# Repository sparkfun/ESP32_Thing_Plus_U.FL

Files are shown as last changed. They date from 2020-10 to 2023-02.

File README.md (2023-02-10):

SparkFun ESP32 Thing Plus (U.FL)
========================================

SparkFun ESP32 Thing Plus U.FL (https://www.sparkfun.com/products/17381)

[*SparkFun ESP32 Thing Plus U.FL (WRL-17381)*](https://www.sparkfun.com/products/17381)

The [SparkFun ESP32 Thing Plus (U.FL)](https://www.sparkfun.com/products/17381) is a comprehensive development platform for [Espressif's ESP32](https://espressif.com/en/products/hardware/esp32/overview). This board has the ESP32-WROOM-32EU version of the module which contains a U.FL connector for your antenna. Like the 8266 and ESP32 Thing, the ESP32 Thing Plus is a **WiFi**-compatible microcontroller with support for **Bluetooth low-energy** (i.e BLE, BT4.0, Bluetooth Smart), a Qwiic adapter, and 21 I/O pins. Add to that a rich set of peripherals ranging from capacitive touch sensors, SD card interface, Ethernet, high-speed SPI, UART, I2S and I<sup>2</sup>C.

Upgraded and easy to use, the Esp32 Thing Plus will help make it the foundation of IoT and connected projects for many years to come.

Repository Contents
-------------------

* **/Hardware** - Eagle design files (.brd, .sch)
* **/Hardware/Production** - Production panel files (gerbers, .brd)

Documentation
--------------
* **[Hookup Guide](https://learn.sparkfun.com/tutorials/esp32-thing-plus-hookup-guide)** - Basic hookup guide for the ESP32 Thing Plus.
* **[SparkFun Fritzing repo](https://github.com/sparkfun/Fritzing_Parts)** - Fritzing diagrams for SparkFun products.
* **[SparkFun Graphical Datasheets](https://github.com/sparkfun/Graphical_Datasheets)** -Graphical Datasheets for various SparkFun products.

Product Versions
----------------
* [WRL-17381](https://www.sparkfun.com/products/17381)- v1.0, Initial Release

License Information
-------------------

This product is _**open source**_! 

Please review the LICENSE.md file for license information. 

If you have any questions or concerns on licensing, please contact technical support on our [SparkFun forums](https://forum.sparkfun.com/viewforum.php?f=152).

Distributed as-is; no warranty is given.

- Your friends at SparkFun.

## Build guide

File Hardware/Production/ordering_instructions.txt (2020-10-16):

panel size, 131x191mm
PCB thickness, 1.6mm
number of layers, 4
soldermask color, Red
silkscreen color, White
oz copper, 1oz
finish, HASL lead free
stencils, top
pcs per panel, 15
min trace width, 0.2032mm / 0.0080in
min drill size, 0.2540mm / 0.0100in
filename to layer stackup 1/2/3/4: GTL, GL2, GL3, GBL

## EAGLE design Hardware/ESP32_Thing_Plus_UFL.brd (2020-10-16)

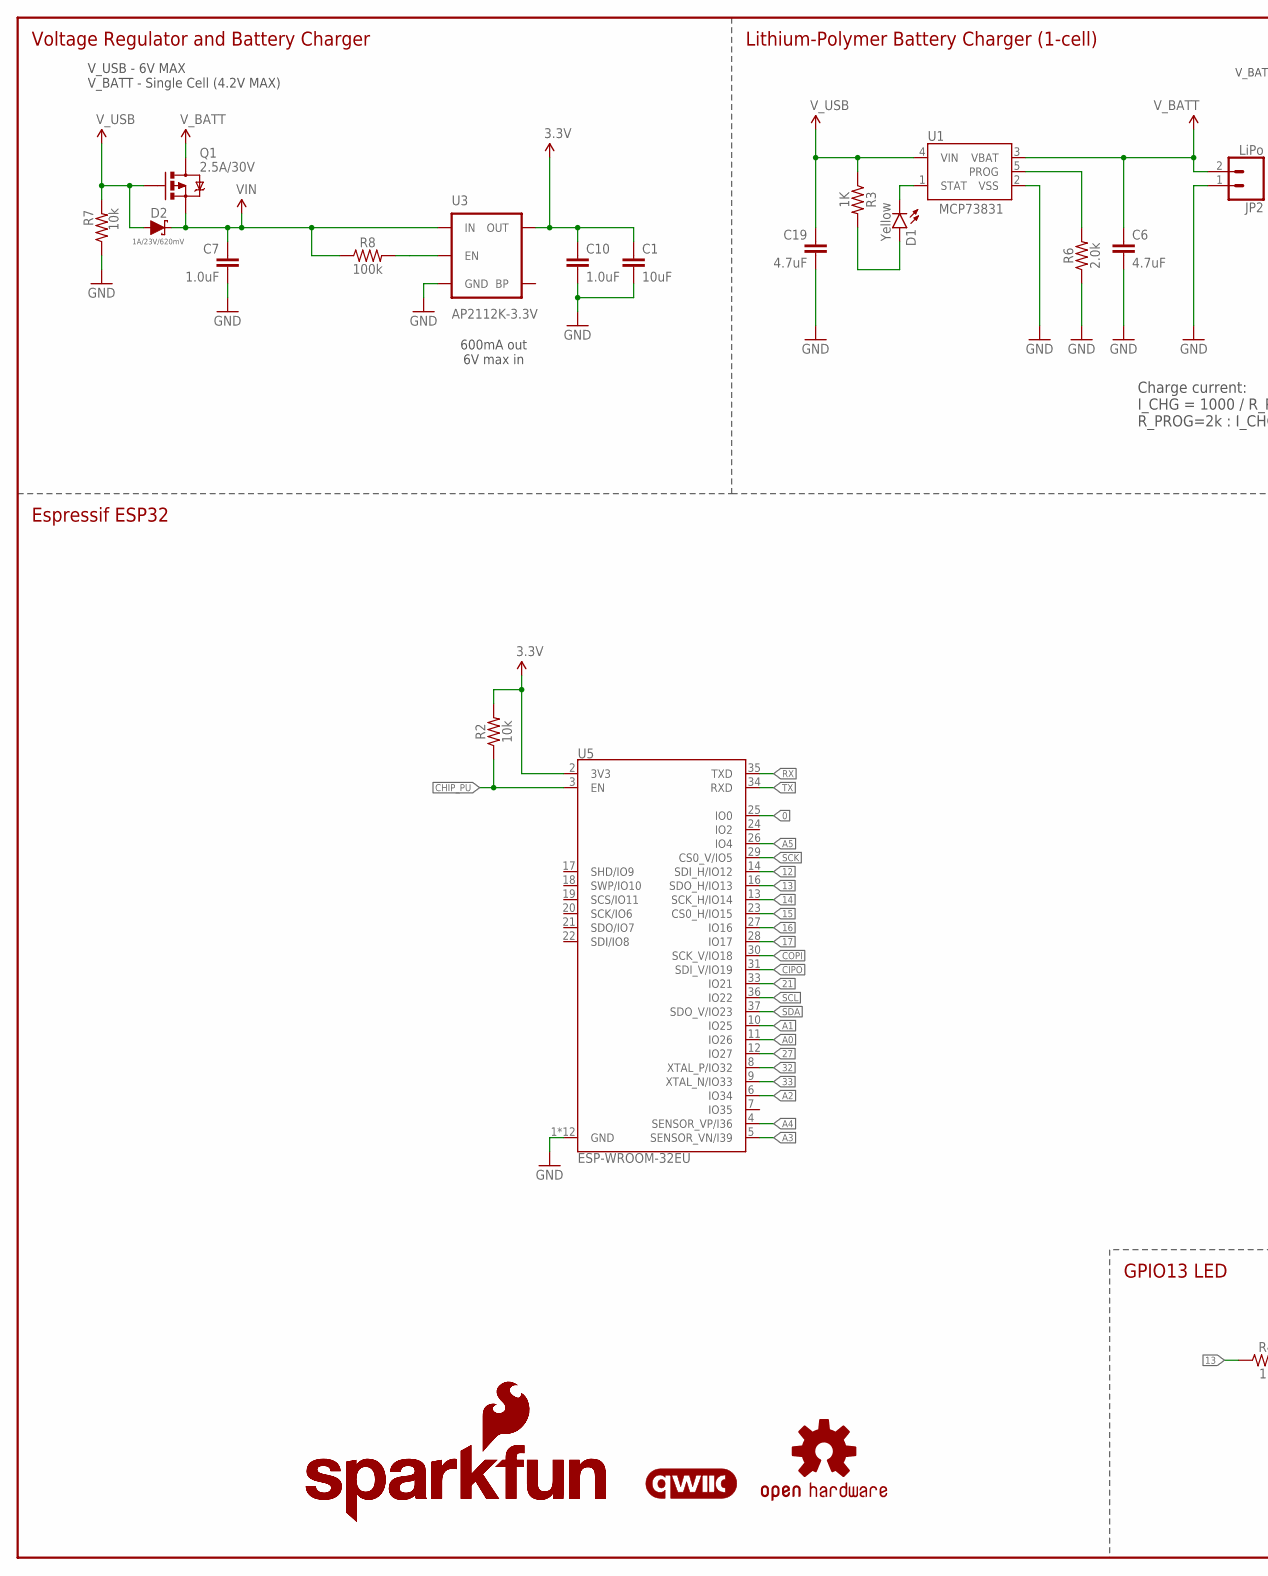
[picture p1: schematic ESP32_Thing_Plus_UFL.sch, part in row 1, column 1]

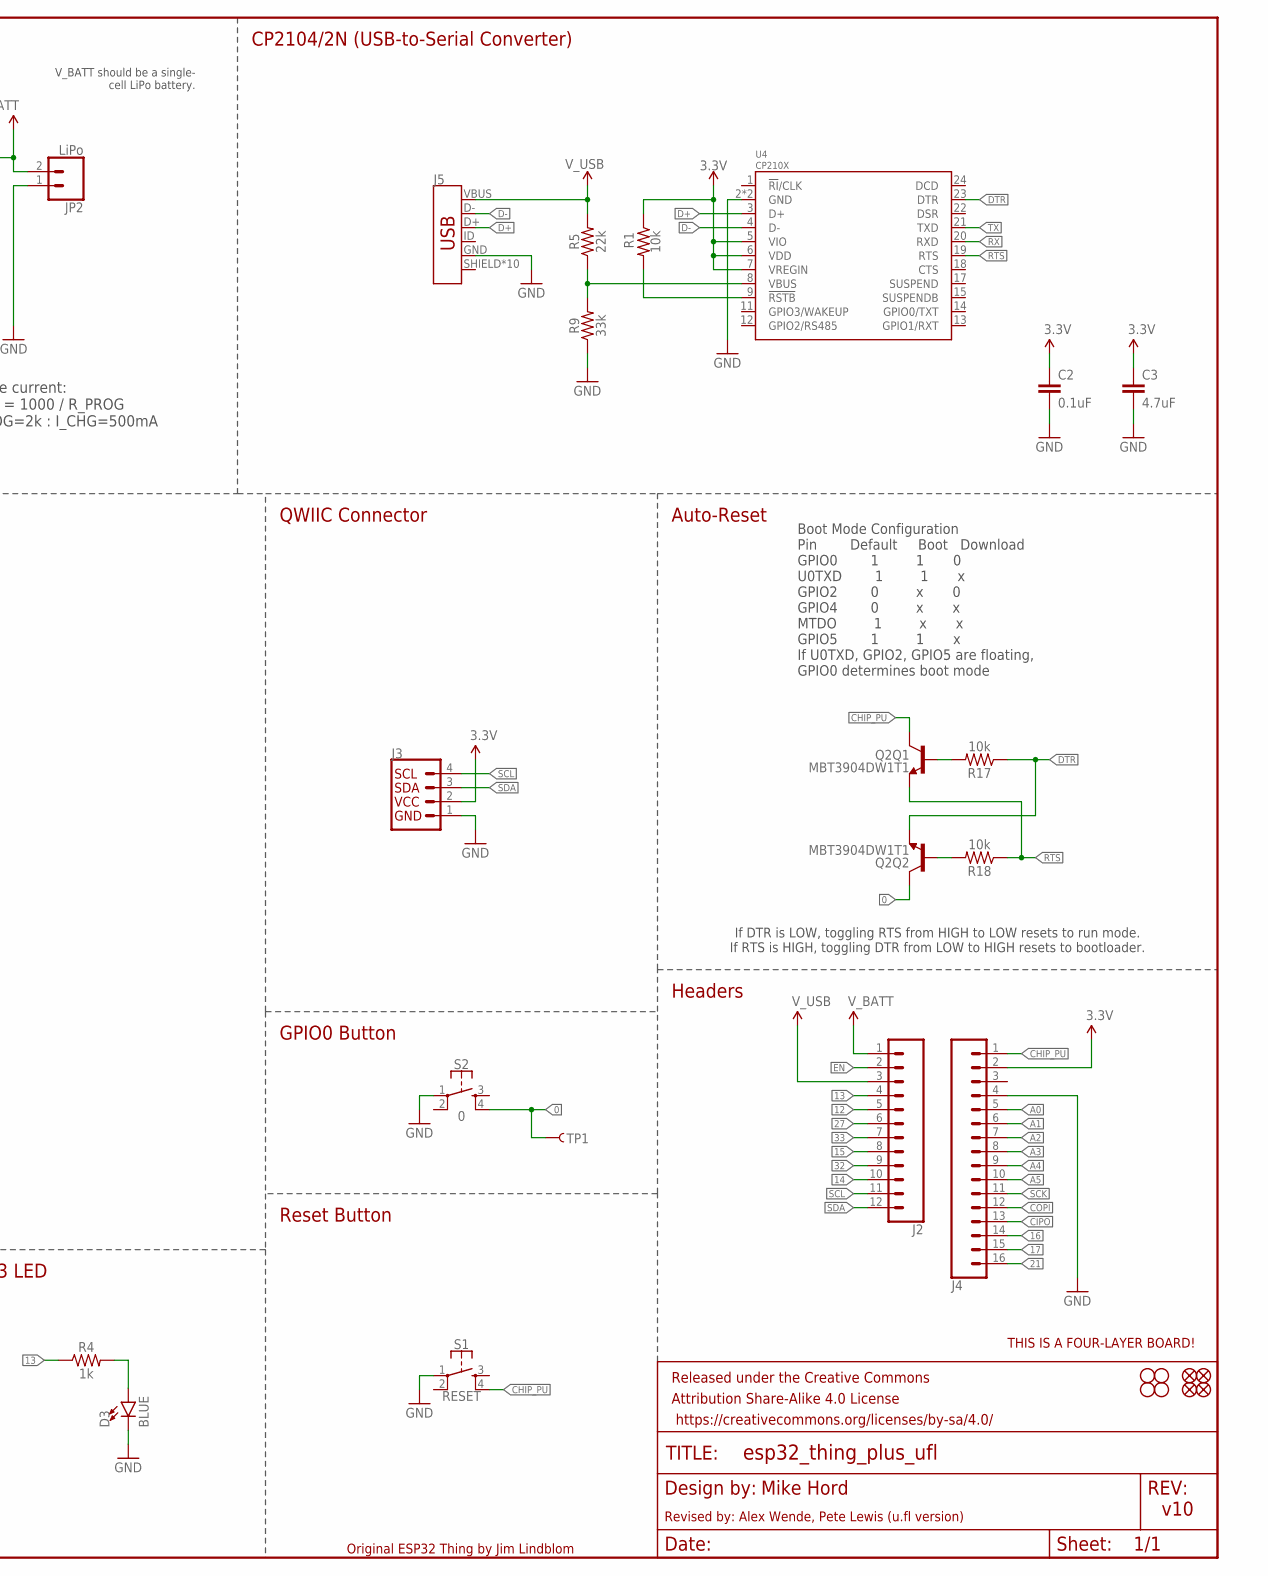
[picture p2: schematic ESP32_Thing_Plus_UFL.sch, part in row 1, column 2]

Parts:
C1: 10uF; 0603
C2: 0.1uF; 0402-TIGHT
C3, C6, C19: 4.7uF; 0402-TIGHT
C7, C10: 1.0uF; 0402-TIGHT
D1: Yellow; LED-0603
D2: 1A/23V/620mV; SOD-323
D3: BLUE; LED-0603
FD1, FD2, FD3, FD4: FIDUCIALUFIDUCIAL; FIDUCIAL-MICRO
FRAME1: FRAME-LEDGER; CREATIVE_COMMONS
H1, H2, H3, H4: STAND-OFFTIGHT; STAND-OFF-TIGHT
J2: CONN_12SM_SQ_NO_SILK; 1X12_SM_SQ_NOSILK
J3: QWIIC_CONNECTORJS-1MM; 1X04_1MM_RA
J4: CONN_161X16_SM_SQ_NOSILK; 1X16_SM_SQ_NOSILK
J5: USB_MICRO-B_HALF_PTH_MILL; USB-MICROB-PTH-MILL
JP2: LiPo; JST-2-SMD
LOGO2: OSHW-LOGOMINI; OSHW-LOGO-MINI
LOGO3, LOGO5: SFE_LOGO_NAME_FLAME.1_INCH; SFE_LOGO_NAME_FLAME_.1
LOGO4: FOUR_LAYER_WARNING
LOGO6: QWIIC_LOGO_5MM; QWIIC_5MM
Q1: 2.5A/30V; SOT23-3@1
Q2: MBT3904DW1T1; SC70-6
R1, R2, R7, R17, R18: 10k; 0603
R3: 1K; 0603
R4: 1k; 0603
R5: 22k; 0402-TIGHT
R6: 2.0k; 0603
R8: 100k; 0402-TIGHT
R9: 33k; 0402-TIGHT
S1: RESET; TACTILE_SWITCH_SMD_4.6X2.8MM
S2: 0; TACTILE_SWITCH_SMD_4.6X2.8MM
TP1: TEST-POINTTP_15TH_THRU; TP_15TH
U1: MCP73831; SOT23-5
U3: AP2112K-3.3V; SOT23-5
U4: CP210X; QFN24
U5: ESP-WROOM-32EU; ESP-WROOM-32EU-NARROW

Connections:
0: Q2.6 (C), S2.4, TP1.P$1, U5.25 (IO0)
3.3V: C1.1, C2.1, C3.1, C10.1, J3.2, J4.2, R1.1, R2.2, U3.5 (OUT), U4.5 (VIO), U4.6 (VDD), U4.7 (VREGIN), U5.2 (3V3)
12: J2.5, U5.14 (SDI_H/IO12)
13: J2.4, R4.1, U5.16 (SDO_H/IO13)
14: J2.10, U5.13 (SCK_H/IO14)
15: J2.8, U5.23 (CS0_H/IO15)
16: J4.14, U5.27 (IO16)
17: J4.15, U5.28 (IO17)
21: J4.16, U5.33 (IO21)
27: J2.6, U5.12 (IO27)
32: J2.9, U5.8 (XTAL_P/IO32)
33: J2.7, U5.9 (XTAL_N/IO33)
A0: J4.5, U5.11 (IO26)
A1: J4.6, U5.10 (IO25)
A2: J4.7, U5.6 (IO34)
A3: J4.8, U5.5 (SENSOR_VN/I39)
A4: J4.9, U5.4 (SENSOR_VP/I36)
A5: J4.10, U5.26 (IO4)
CHG: D1.C, U1.1 (STAT)
CHIP_PU: J4.1, Q2.3 (C), R2.1, S1.4, U5.3 (EN)
CIPO: J4.13, U5.31 (SDI_V/IO19)
COPI: J4.12, U5.30 (SCK_V/IO18)
D+: J5.D+, U4.3 (D+)
D-: J5.D-, U4.4 (D-)
DTR: Q2.1 (E), R17.1, U4.23 (DTR)
EN: J2.2, R8.2, U3.3 (EN)
GND: C1.2, C2.2, C3.2, C6.2, C7.2, C10.2, C19.2, D3.C, J3.1, J4.4, J5.GND, JP2.1 (2), R6.1, R7.1, R9.1, S1.1, S2.1, U1.2 (VSS), U3.2 (GND), U4.2 (GND), U4.PAD (GND), U5.1 (GND), U5.15 (GND), U5.38 (GND), U5.GND, U5.P$1 (GND), U5.P$2 (GND), U5.P$3 (GND), U5.P$4 (GND), U5.P$5 (GND), U5.P$6 (GND), U5.P$7 (GND), U5.P$8 (GND)
unnamed: R1.2, U4.9 (!RSTB)
unnamed: D3.A, R4.2
unnamed: R5.1, R9.2, U4.8 (VBUS)
unnamed: Q2.5 (B), R17.2
unnamed: Q2.2 (B), R18.2
unnamed: R6.2, U1.5 (PROG)
unnamed: D1.A, R3.2
RTS: Q2.4 (E), R18.1, U4.19 (RTS)
RX: U4.20 (RXD), U5.35 (TXD)
SCK: J4.11, U5.29 (CS0_V/IO5)
SCL: J2.11, J3.4, U5.36 (IO22)
SDA: J2.12, J3.3, U5.37 (SDO_V/IO23)
TX: U4.21 (TXD), U5.34 (RXD)
VIN: C7.1, D2.C, Q1.2 (S), R8.1, U3.1 (IN)
V_BATT: C6.1, J2.1, JP2.2 (1), Q1.3 (D), U1.3 (VBAT)
V_USB: C19.1, D2.A, J2.3, J5.VBUS, Q1.1 (G), R3.1, R5.2, R7.2, U1.4 (VIN)

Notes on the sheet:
Boot Mode Configuration Pin Default Boot Download GPIO0 1 1 0 U0TXD 1 1 x GPIO2 0 x 0 GPIO4 0 x x MTDO 1 x x GPIO5 1 1 x If U0TXD, GPIO2, GPIO5 are floating, GPIO0 determines boot mode
CP2104/2N (USB-to-Serial Converter)
V_BATT should be a single- cell LiPo battery.
Charge current: I_CHG = 1000 / R_PROG R_PROG=2k : I_CHG=500mA
Voltage Regulator and Battery Charger
Lithium-Polymer Battery Charger (1-cell)
600mA out 6V max in
Auto-Reset
Espressif ESP32
Reset Button
Headers
v10
Original ESP32 Thing by Jim Lindblom
If DTR is LOW, toggling RTS from HIGH to LOW resets to run mode. If RTS is HIGH, toggling DTR from LOW to HIGH resets to bootloader.
QWIIC Connector
Mike Hord
GPIO13 LED
GPIO0 Button
Revised by: Alex Wende, Pete Lewis (u.fl version)
V_USB - 6V MAX V_BATT - Single Cell (4.2V MAX)

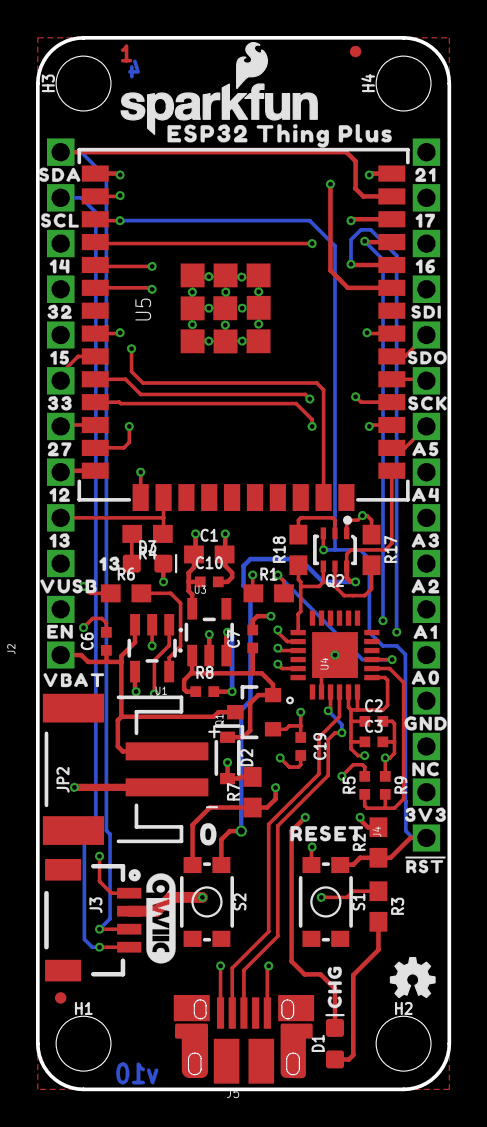
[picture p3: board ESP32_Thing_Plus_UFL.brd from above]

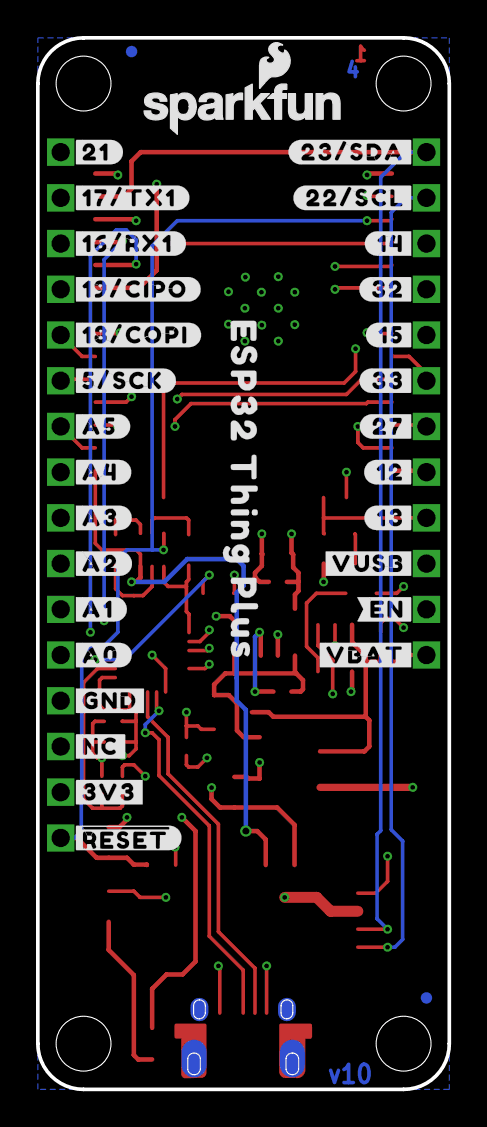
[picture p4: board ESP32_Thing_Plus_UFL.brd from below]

Board: 4 copper layers, 22.9 x 58.4 mm, 112 parts (32 on the bottom side), 43 nets.

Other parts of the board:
U$1: ESP32_THING_PLUS_0
U$2: SDI0
U$3: #21#0
U$4: #17#TX1#0
U$5: #16#RX1#0
U$6: SDO0
U$7: #RST#0
U$8: #19#CIPO#0
U$10: #18#COPI#0
U$11: #5#SCK#0
U$12: #A5#0
U$19: #A4#0
U$21: #A3#0
U$22: #A2#0
U$24: ESP32_THING_PLUS0
U$25: SDA0
U$26: SCL0
U$27: #A1#0
U$28: #A0#0
U$31: #23#SDA#0
U$32: #GND#0
U$33: #22#SCL#0
U$34: #14#0
U$35: #32#0
U$36: #15#0
U$37: #33#0
U$38: #27#0
U$39: #12#0
U$40: #13#0
U$41: #VUSB#0
U$42: #VBAT#0
U$43: #EN#0
U$44: #NC#0
U$45: #3V3#0
U$46: ##RESET##0
U$58: 140
U$59: ORDERING_INSTRUCTIONS
U$68: 320
U$69: 150
U$70: 330
U$71: 270
U$72: 120
U$73, U$74: 130
U$75: VUSB0
U$76: EN0
U$77: VBAT0
U$78: CHG0
U$79: RESET0
U$81: 3V30
U$82: NC0
U$83: GND0
U$84: A00
U$85: A10
U$86: A20
U$87: A30
U$88: A40
U$89: A50
U$90: SCK0
U$93: 160
U$94: 170
U$95: 210
U$96: 00

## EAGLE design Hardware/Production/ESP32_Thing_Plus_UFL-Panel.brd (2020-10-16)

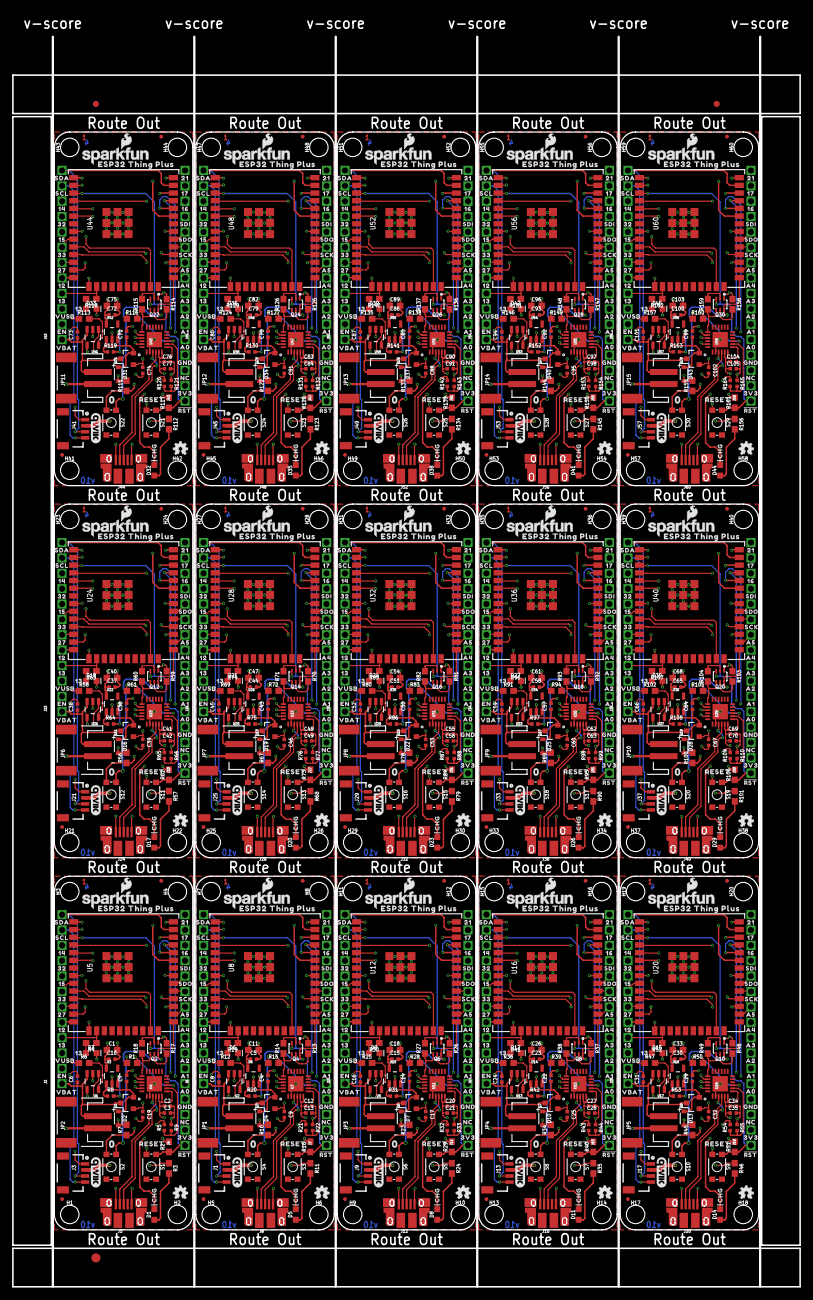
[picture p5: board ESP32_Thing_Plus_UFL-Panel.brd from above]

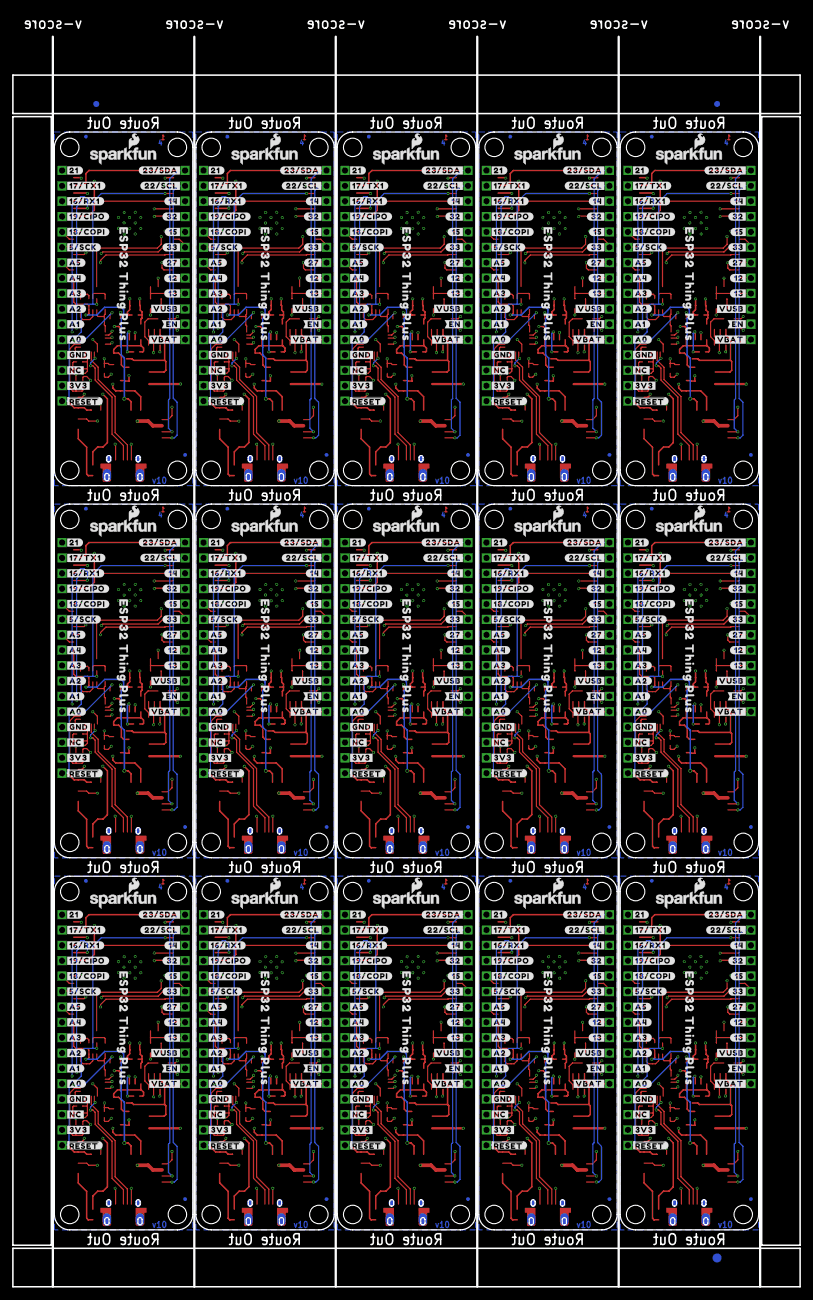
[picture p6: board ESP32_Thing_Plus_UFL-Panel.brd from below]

Board: 4 copper layers, 130.0 x 206.5 mm, 1671 parts (483 on the bottom side), 645 nets.

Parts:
C1, C11, C18, C26, C33, C40, C47, C54, C61, C68, C75, C82, C89, C96, C103: 10uF; 0603
C2, C12, C20, C27, C34, C41, C48, C55, C62, C69, C76, C83, C90, C97, C104: 0.1uF; 0402-TIGHT
C3, C6, C8, C9, C13, C16, C17, C19, C21, C24, C25, C28, C31, C32, C35, C38, C39, C42, C45, C46, C49, C52, C53, C56, C59, C60, C63, C66, C67, C70, C73, C74, C77, C80, C81, C84, C87, C88, C91, C94, C95, C98, C101, C102, C105: 4.7uF; 0402-TIGHT
C4, C5, C7, C10, C14, C15, C22, C23, C29, C30, C36, C37, C43, C44, C50, C51, C57, C58, C64, C65, C71, C72, C78, C79, C85, C86, C92, C93, C99, C100: 1.0uF; 0402-TIGHT
D1, D5, D8, D11, D14, D17, D20, D23, D26, D29, D32, D35, D38, D41, D44: Yellow; LED-0603
D2, D4, D7, D10, D13, D16, D19, D22, D25, D28, D31, D34, D37, D40, D43: 1A/23V/620mV; SOD-323
D3, D6, D9, D12, D15, D18, D21, D24, D27, D30, D33, D36, D39, D42, D45: BLUE; LED-0603
E$1, E$2, E$3, E$4: FIDUCIAL-1X2
E$5, E$6: FIDUCIAL-1.5X3
FD1, FD2, FD3, FD4, FD5, FD6, FD7, FD8, FD9, FD10, FD11, FD12, FD13, FD14, FD15, FD16, FD17, FD18, FD19, FD20, FD21, FD22, FD23, FD24, FD25, FD26, FD27, FD28, FD29, FD30, FD31, FD32, FD33, FD34, FD35, FD36, FD37, FD38, FD39, FD40, FD41, FD42, FD43, FD44, FD45, FD46, FD47, FD48, FD49, FD50, FD51, FD52, FD53, FD54, FD55, FD56, FD57, FD58, FD59, FD60: FIDUCIALUFIDUCIAL; FIDUCIAL-MICRO
H1, H2, H3, H4, H5, H6, H7, H8, H9, H10, H11, H12, H13, H14, H15, H16, H17, H18, H19, H20, H21, H22, H23, H24, H25, H26, H27, H28, H29, H30, H31, H32, H33, H34, H35, H36, H37, H38, H39, H40, H41, H42, H43, H44, H45, H46, H47, H48, H49, H50, H51, H52, H53, H54, H55, H56, H57, H58, H59, H60: STAND-OFFTIGHT; STAND-OFF-TIGHT
J1, J3, J9, J13, J17, J21, J25, J29, J33, J37, J41, J45, J49, J53, J57: 1X04_1MM_RA
J2, J6, J10, J14, J18, J22, J26, J30, J34, J38, J42, J46, J50, J54, J58: 1X12_SM_SQ_NOSILK
J4, J7, J11, J15, J19, J23, J27, J31, J35, J39, J43, J47, J51, J55, J59: 1X16_SM_SQ_NOSILK
J5, J8, J12, J16, J20, J24, J28, J32, J36, J40, J44, J48, J52, J56, J60: USB-MICROB-PTH-MILL
JP1, JP2, JP3, JP4, JP5, JP6, JP7, JP8, JP9, JP10, JP11, JP12, JP13, JP14, JP15: LiPo; JST-2-SMD
LOGO1, LOGO2, LOGO11, LOGO16, LOGO21, LOGO26, LOGO31, LOGO36, LOGO41, LOGO46, LOGO51, LOGO56, LOGO61, LOGO66, LOGO71: OSHW-LOGOMINI; OSHW-LOGO-MINI
LOGO3, LOGO5, LOGO7, LOGO9, LOGO12, LOGO14, LOGO17, LOGO19, LOGO22, LOGO24, LOGO27, LOGO29, LOGO32, LOGO34, LOGO37, LOGO39, LOGO42, LOGO44, LOGO47, LOGO49, LOGO52, LOGO54, LOGO57, LOGO59, LOGO62, LOGO64, LOGO67, LOGO69, LOGO72, LOGO74: SFE_LOGO_NAME_FLAME.1_INCH; SFE_LOGO_NAME_FLAME_.1
LOGO4, LOGO8, LOGO13, LOGO18, LOGO23, LOGO28, LOGO33, LOGO38, LOGO43, LOGO48, LOGO53, LOGO58, LOGO63, LOGO68, LOGO73: FOUR_LAYER_WARNING
LOGO6, LOGO10, LOGO15, LOGO20, LOGO25, LOGO30, LOGO35, LOGO40, LOGO45, LOGO50, LOGO55, LOGO60, LOGO65, LOGO70, LOGO75: QWIIC_LOGO_5MM; QWIIC_5MM
Q1, Q3, Q5, Q7, Q9, Q11, Q13, Q15, Q17, Q19, Q21, Q23, Q25, Q27, Q29: 2.5A/30V; SOT23-3@1
Q2, Q4, Q6, Q8, Q10, Q12, Q14, Q16, Q18, Q20, Q22, Q24, Q26, Q28, Q30: MBT3904DW1T1; SC70-6
R1, R2, R7, R10, R13, R14, R15, R16, R17, R18, R23, R26, R27, R28, R29, R34, R37, R38, R39, R40, R45, R48, R49, R50, R51, R56, R59, R60, R61, R62, R67, R70, R71, R72, R73, R78, R81, R82, R83, R84, R89, R92, R93, R94, R95, R100, R103, R104, R105, R106, R111, R114, R115, R116, R117, R122, R125, R126, R127, R128, R133, R136, R137, R138, R139, R144, R147, R148, R149, R150, R155, R158, R159, R160, R161: 10k; 0603
R3, R11, R24, R35, R46, R57, R68, R79, R90, R101, R112, R123, R134, R145, R156: 1K; 0603
R4, R19, R30, R41, R52, R63, R74, R85, R96, R107, R118, R129, R140, R151, R162: 1k; 0603
R5, R21, R32, R43, R54, R65, R76, R87, R98, R109, R120, R131, R142, R153, R164: 22k; 0402-TIGHT
R6, R12, R25, R36, R47, R58, R69, R80, R91, R102, R113, R124, R135, R146, R157: 2.0k; 0603
R8, R20, R31, R42, R53, R64, R75, R86, R97, R108, R119, R130, R141, R152, R163: 100k; 0402-TIGHT
R9, R22, R33, R44, R55, R66, R77, R88, R99, R110, R121, R132, R143, R154, R165: 33k; 0402-TIGHT
S1, S3, S5, S7, S9, S11, S13, S15, S17, S19, S21, S23, S25, S27, S29: RESET; TACTILE_SWITCH_SMD_4.6X2.8MM
S2, S4, S6, S8, S10, S12, S14, S16, S18, S20, S22, S24, S26, S28, S30: 0; TACTILE_SWITCH_SMD_4.6X2.8MM
TP1, TP2, TP3, TP4, TP5, TP6, TP7, TP8, TP9, TP10, TP11, TP12, TP13, TP14, TP15: TP_15TH
U1, U2, U9, U13, U17, U21, U25, U29, U33, U37, U41, U45, U49, U53, U57: MCP73831; SOT23-5
U3, U6, U10, U14, U18, U22, U26, U30, U34, U38, U42, U46, U50, U54, U58: AP2112K-3.3V; SOT23-5
U4, U7, U11, U15, U19, U23, U27, U31, U35, U39, U43, U47, U51, U55, U59: CP210X; QFN24
U5, U8, U12, U16, U20, U24, U28, U32, U36, U40, U44, U48, U52, U56, U60: ESP-WROOM-32EU; ESP-WROOM-32EU-NARROW
U$1, U$123, U$186, U$249, U$312, U$375, U$438, U$501, U$564, U$627, U$690, U$753, U$816, U$879, U$942: ESP32_THING_PLUS_0
U$2, U$124, U$187, U$250, U$313, U$376, U$439, U$502, U$565, U$628, U$691, U$754, U$817, U$880, U$943: SDI0
U$3, U$107, U$170, U$233, U$296, U$359, U$422, U$485, U$548, U$611, U$674, U$737, U$800, U$863, U$926: #21#0
U$4, U$108, U$171, U$234, U$297, U$360, U$423, U$486, U$549, U$612, U$675, U$738, U$801, U$864, U$927: #17#TX1#0
U$5, U$109, U$172, U$235, U$298, U$361, U$424, U$487, U$550, U$613, U$676, U$739, U$802, U$865, U$928: #16#RX1#0
U$6, U$125, U$188, U$251, U$314, U$377, U$440, U$503, U$566, U$629, U$692, U$755, U$818, U$881, U$944: SDO0
U$7, U$126, U$189, U$252, U$315, U$378, U$441, U$504, U$567, U$630, U$693, U$756, U$819, U$882, U$945: #RST#0
U$8, U$110, U$173, U$236, U$299, U$362, U$425, U$488, U$551, U$614, U$677, U$740, U$803, U$866, U$929: #19#CIPO#0
U$9, U$59, U$127, U$190, U$253, U$316, U$379, U$442, U$505, U$568, U$631, U$694, U$757, U$820, U$883: ORDERING_INSTRUCTIONS
U$10, U$111, U$174, U$237, U$300, U$363, U$426, U$489, U$552, U$615, U$678, U$741, U$804, U$867, U$930: #18#COPI#0
U$11, U$112, U$175, U$238, U$301, U$364, U$427, U$490, U$553, U$616, U$679, U$742, U$805, U$868, U$931: #5#SCK#0
U$12, U$113, U$176, U$239, U$302, U$365, U$428, U$491, U$554, U$617, U$680, U$743, U$806, U$869, U$932: #A5#0
U$13, U$24, U$128, U$191, U$254, U$317, U$380, U$443, U$506, U$569, U$632, U$695, U$758, U$821, U$884: ESP32_THING_PLUS0
U$14, U$25, U$129, U$192, U$255, U$318, U$381, U$444, U$507, U$570, U$633, U$696, U$759, U$822, U$885: SDA0
U$15, U$26, U$130, U$193, U$256, U$319, U$382, U$445, U$508, U$571, U$634, U$697, U$760, U$823, U$886: SCL0
U$16, U$58, U$131, U$194, U$257, U$320, U$383, U$446, U$509, U$572, U$635, U$698, U$761, U$824, U$887: 140
U$17, U$68, U$132, U$195, U$258, U$321, U$384, U$447, U$510, U$573, U$636, U$699, U$762, U$825, U$888: 320
U$18, U$69, U$133, U$196, U$259, U$322, U$385, U$448, U$511, U$574, U$637, U$700, U$763, U$826, U$889: 150
U$19, U$114, U$177, U$240, U$303, U$366, U$429, U$492, U$555, U$618, U$681, U$744, U$807, U$870, U$933: #A4#0
U$20, U$70, U$134, U$197, U$260, U$323, U$386, U$449, U$512, U$575, U$638, U$701, U$764, U$827, U$890: 330
U$21, U$115, U$178, U$241, U$304, U$367, U$430, U$493, U$556, U$619, U$682, U$745, U$808, U$871, U$934: #A3#0
U$22, U$116, U$179, U$242, U$305, U$368, U$431, U$494, U$557, U$620, U$683, U$746, U$809, U$872, U$935: #A2#0
U$23, U$71, U$135, U$198, U$261, U$324, U$387, U$450, U$513, U$576, U$639, U$702, U$765, U$828, U$891: 270
U$27, U$117, U$180, U$243, U$306, U$369, U$432, U$495, U$558, U$621, U$684, U$747, U$810, U$873, U$936: #A1#0
U$28, U$118, U$181, U$244, U$307, U$370, U$433, U$496, U$559, U$622, U$685, U$748, U$811, U$874, U$937: #A0#0
U$29, U$72, U$136, U$199, U$262, U$325, U$388, U$451, U$514, U$577, U$640, U$703, U$766, U$829, U$892: 120
U$30, U$47, U$73, U$74, U$137, U$138, U$200, U$201, U$263, U$264, U$326, U$327, U$389, U$390, U$452, U$453, U$515, U$516, U$578, U$579, U$641, U$642, U$704, U$705, U$767, U$768, U$830, U$831, U$893, U$894: 130
U$31, U$91, U$158, U$221, U$284, U$347, U$410, U$473, U$536, U$599, U$662, U$725, U$788, U$851, U$914: #23#SDA#0
U$32, U$119, U$182, U$245, U$308, U$371, U$434, U$497, U$560, U$623, U$686, U$749, U$812, U$875, U$938: #GND#0
U$33, U$92, U$159, U$222, U$285, U$348, U$411, U$474, U$537, U$600, U$663, U$726, U$789, U$852, U$915: #22#SCL#0
U$34, U$97, U$160, U$223, U$286, U$349, U$412, U$475, U$538, U$601, U$664, U$727, U$790, U$853, U$916: #14#0
U$35, U$98, U$161, U$224, U$287, U$350, U$413, U$476, U$539, U$602, U$665, U$728, U$791, U$854, U$917: #32#0
U$36, U$99, U$162, U$225, U$288, U$351, U$414, U$477, U$540, U$603, U$666, U$729, U$792, U$855, U$918: #15#0
U$37, U$100, U$163, U$226, U$289, U$352, U$415, U$478, U$541, U$604, U$667, U$730, U$793, U$856, U$919: #33#0
U$38, U$101, U$164, U$227, U$290, U$353, U$416, U$479, U$542, U$605, U$668, U$731, U$794, U$857, U$920: #27#0
U$39, U$102, U$165, U$228, U$291, U$354, U$417, U$480, U$543, U$606, U$669, U$732, U$795, U$858, U$921: #12#0
U$40, U$103, U$166, U$229, U$292, U$355, U$418, U$481, U$544, U$607, U$670, U$733, U$796, U$859, U$922: #13#0
U$41, U$104, U$167, U$230, U$293, U$356, U$419, U$482, U$545, U$608, U$671, U$734, U$797, U$860, U$923: #VUSB#0
U$42, U$105, U$168, U$231, U$294, U$357, U$420, U$483, U$546, U$609, U$672, U$735, U$798, U$861, U$924: #VBAT#0
U$43, U$106, U$169, U$232, U$295, U$358, U$421, U$484, U$547, U$610, U$673, U$736, U$799, U$862, U$925: #EN#0
U$44, U$120, U$183, U$246, U$309, U$372, U$435, U$498, U$561, U$624, U$687, U$750, U$813, U$876, U$939: #NC#0
U$45, U$121, U$184, U$247, U$310, U$373, U$436, U$499, U$562, U$625, U$688, U$751, U$814, U$877, U$940: #3V3#0
U$46, U$122, U$185, U$248, U$311, U$374, U$437, U$500, U$563, U$626, U$689, U$752, U$815, U$878, U$941: ##RESET##0
U$48, U$75, U$139, U$202, U$265, U$328, U$391, U$454, U$517, U$580, U$643, U$706, U$769, U$832, U$895: VUSB0
U$49, U$76, U$140, U$203, U$266, U$329, U$392, U$455, U$518, U$581, U$644, U$707, U$770, U$833, U$896: EN0
U$50, U$77, U$141, U$204, U$267, U$330, U$393, U$456, U$519, U$582, U$645, U$708, U$771, U$834, U$897: VBAT0
U$51, U$78, U$142, U$205, U$268, U$331, U$394, U$457, U$520, U$583, U$646, U$709, U$772, U$835, U$898: CHG0
U$52, U$79, U$143, U$206, U$269, U$332, U$395, U$458, U$521, U$584, U$647, U$710, U$773, U$836, U$899: RESET0
U$53, U$81, U$144, U$207, U$270, U$333, U$396, U$459, U$522, U$585, U$648, U$711, U$774, U$837, U$900: 3V30
U$54, U$82, U$145, U$208, U$271, U$334, U$397, U$460, U$523, U$586, U$649, U$712, U$775, U$838, U$901: NC0
U$55, U$83, U$146, U$209, U$272, U$335, U$398, U$461, U$524, U$587, U$650, U$713, U$776, U$839, U$902: GND0
U$56, U$84, U$147, U$210, U$273, U$336, U$399, U$462, U$525, U$588, U$651, U$714, U$777, U$840, U$903: A00
U$57, U$85, U$148, U$211, U$274, U$337, U$400, U$463, U$526, U$589, U$652, U$715, U$778, U$841, U$904: A10
U$60, U$86, U$149, U$212, U$275, U$338, U$401, U$464, U$527, U$590, U$653, U$716, U$779, U$842, U$905: A20
U$61, U$87, U$150, U$213, U$276, U$339, U$402, U$465, U$528, U$591, U$654, U$717, U$780, U$843, U$906: A30
U$62, U$88, U$151, U$214, U$277, U$340, U$403, U$466, U$529, U$592, U$655, U$718, U$781, U$844, U$907: A40
U$63, U$89, U$152, U$215, U$278, U$341, U$404, U$467, U$530, U$593, U$656, U$719, U$782, U$845, U$908: A50
U$64, U$90, U$153, U$216, U$279, U$342, U$405, U$468, U$531, U$594, U$657, U$720, U$783, U$846, U$909: SCK0
U$65, U$93, U$154, U$217, U$280, U$343, U$406, U$469, U$532, U$595, U$658, U$721, U$784, U$847, U$910: 160
U$66, U$94, U$155, U$218, U$281, U$344, U$407, U$470, U$533, U$596, U$659, U$722, U$785, U$848, U$911: 170
U$67, U$95, U$156, U$219, U$282, U$345, U$408, U$471, U$534, U$597, U$660, U$723, U$786, U$849, U$912: 210
U$80, U$96, U$157, U$220, U$283, U$346, U$409, U$472, U$535, U$598, U$661, U$724, U$787, U$850, U$913: 00

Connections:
0: Q2.6, S2.4, TP1.P$1, U5.25
1: Q4.6, S4.4, TP2.P$1, U8.25
2: J6.10, U8.13
3: J6.9, U8.8
3.3V: C1.1, C2.1, C3.1, C10.1, J3.2, J4.2, R1.1, R2.2, U3.5, U4.5, U4.6, U4.7, U5.2
3.3V1: C5.1, C11.1, C12.1, C13.1, J1.2, J7.2, R15.1, R16.2, U6.5, U7.5, U7.6, U7.7, U8.2
3.3V2: C15.1, C18.1, C20.1, C21.1, J9.2, J11.2, R28.1, R29.2, U10.5, U11.5, U11.6, U11.7, U12.2
3.3V3: C23.1, C26.1, C27.1, C28.1, J13.2, J15.2, R39.1, R40.2, U14.5, U15.5, U15.6, U15.7, U16.2
3.3V4: C30.1, C33.1, C34.1, C35.1, J17.2, J19.2, R50.1, R51.2, U18.5, U19.5, U19.6, U19.7, U20.2
3.3V5: C37.1, C40.1, C41.1, C42.1, J21.2, J23.2, R61.1, R62.2, U22.5, U23.5, U23.6, U23.7, U24.2
3.3V6: C44.1, C47.1, C48.1, C49.1, J25.2, J27.2, R72.1, R73.2, U26.5, U27.5, U27.6, U27.7, U28.2
3.3V7: C51.1, C54.1, C55.1, C56.1, J29.2, J31.2, R83.1, R84.2, U30.5, U31.5, U31.6, U31.7, U32.2
3.3V8: C58.1, C61.1, C62.1, C63.1, J33.2, J35.2, R94.1, R95.2, U34.5, U35.5, U35.6, U35.7, U36.2
3.3V9: C65.1, C68.1, C69.1, C70.1, J37.2, J39.2, R105.1, R106.2, U38.5, U39.5, U39.6, U39.7, U40.2
3.3V10: C72.1, C75.1, C76.1, C77.1, J41.2, J43.2, R116.1, R117.2, U42.5, U43.5, U43.6, U43.7, U44.2
3.3V11: C79.1, C82.1, C83.1, C84.1, J45.2, J47.2, R127.1, R128.2, U46.5, U47.5, U47.6, U47.7, U48.2
3.3V12: C86.1, C89.1, C90.1, C91.1, J49.2, J51.2, R138.1, R139.2, U50.5, U51.5, U51.6, U51.7, U52.2
3.3V13: C93.1, C96.1, C97.1, C98.1, J53.2, J55.2, R149.1, R150.2, U54.5, U55.5, U55.6, U55.7, U56.2
3.3V14: C100.1, C103.1, C104.1, C105.1, J57.2, J59.2, R160.1, R161.2, U58.5, U59.5, U59.6, U59.7, U60.2
4: J6.8, U8.23
5: J6.7, U8.9
6: J6.6, U8.12
7: J6.5, U8.14
8: J6.4, R19.1, U8.16
9: J7.14, U8.27
10: J7.15, U8.28
11: J7.16, U8.33
12: J2.5, U5.14
13: J2.4, R4.1, U5.16
14: J2.10, U5.13
15: J2.8, U5.23
16: J4.14, U5.27
17: J4.15, U5.28
18: Q6.6, S6.4, TP3.P$1, U12.25
19: J10.10, U12.13
20: J10.9, U12.8
21: J4.16, U5.33
22: J10.8, U12.23
23: J10.7, U12.9
24: J10.6, U12.12
25: J10.5, U12.14
26: J10.4, R30.1, U12.16
27: J2.6, U5.12
28: J11.14, U12.27
29: J11.15, U12.28
30: J11.16, U12.33
31: Q8.6, S8.4, TP4.P$1, U16.25
32: J2.9, U5.8
33: J2.7, U5.9
34: J14.10, U16.13
35: J14.9, U16.8
36: J14.8, U16.23
37: J14.7, U16.9
38: J14.6, U16.12
39: J14.5, U16.14
40: J14.4, R41.1, U16.16
41: J15.14, U16.27
42: J15.15, U16.28
43: J15.16, U16.33
44: Q10.6, S10.4, TP5.P$1, U20.25
45: J18.10, U20.13
46: J18.9, U20.8
47: J18.8, U20.23
48: J18.7, U20.9
49: J18.6, U20.12
50: J18.5, U20.14
51: J18.4, R52.1, U20.16
52: J19.14, U20.27
53: J19.15, U20.28
54: J19.16, U20.33
55: Q12.6, S12.4, TP6.P$1, U24.25
56: J22.10, U24.13
57: J22.9, U24.8
58: J22.8, U24.23
59: J22.7, U24.9
60: J22.6, U24.12
61: J22.5, U24.14
62: J22.4, R63.1, U24.16
63: J23.14, U24.27
64: J23.15, U24.28
65: J23.16, U24.33
66: Q14.6, S14.4, TP7.P$1, U28.25
67: J26.10, U28.13
68: J26.9, U28.8
69: J26.8, U28.23
70: J26.7, U28.9
71: J26.6, U28.12
72: J26.5, U28.14
73: J26.4, R74.1, U28.16
74: J27.14, U28.27
75: J27.15, U28.28
76: J27.16, U28.33
77: Q16.6, S16.4, TP8.P$1, U32.25
78: J30.10, U32.13
79: J30.9, U32.8
80: J30.8, U32.23
81: J30.7, U32.9
82: J30.6, U32.12
83: J30.5, U32.14
84: J30.4, R85.1, U32.16
85: J31.14, U32.27
86: J31.15, U32.28
87: J31.16, U32.33
88: Q18.6, S18.4, TP9.P$1, U36.25
89: J34.10, U36.13
90: J34.9, U36.8
91: J34.8, U36.23
92: J34.7, U36.9
93: J34.6, U36.12
94: J34.5, U36.14
95: J34.4, R96.1, U36.16
96: J35.14, U36.27
97: J35.15, U36.28
98: J35.16, U36.33
99: Q20.6, S20.4, TP10.P$1, U40.25
100: J38.10, U40.13
101: J38.9, U40.8
102: J38.8, U40.23
103: J38.7, U40.9
104: J38.6, U40.12
105: J38.5, U40.14
106: J38.4, R107.1, U40.16
107: J39.14, U40.27
108: J39.15, U40.28
109: J39.16, U40.33
110: Q22.6, S22.4, TP11.P$1, U44.25
111: J42.10, U44.13
112: J42.9, U44.8
113: J42.8, U44.23
114: J42.7, U44.9
115: J42.6, U44.12
116: J42.5, U44.14
117: J42.4, R118.1, U44.16
118: J43.14, U44.27
119: J43.15, U44.28
120: J43.16, U44.33
121: Q24.6, S24.4, TP12.P$1, U48.25
122: J46.10, U48.13
123: J46.9, U48.8
124: J46.8, U48.23
125: J46.7, U48.9
126: J46.6, U48.12
127: J46.5, U48.14
128: J46.4, R129.1, U48.16
129: J47.14, U48.27
130: J47.15, U48.28
131: J47.16, U48.33
132: Q26.6, S26.4, TP13.P$1, U52.25
133: J50.10, U52.13
134: J50.9, U52.8
135: J50.8, U52.23
136: J50.7, U52.9
137: J50.6, U52.12
138: J50.5, U52.14
139: J50.4, R140.1, U52.16
140: J51.14, U52.27
141: J51.15, U52.28
142: J51.16, U52.33
143: Q28.6, S28.4, TP14.P$1, U56.25
144: J54.10, U56.13
145: J54.9, U56.8
146: J54.8, U56.23
147: J54.7, U56.9
148: J54.6, U56.12
149: J54.5, U56.14
150: J54.4, R151.1, U56.16
151: J55.14, U56.27
152: J55.15, U56.28
153: J55.16, U56.33
154: Q30.6, S30.4, TP15.P$1, U60.25
155: J58.10, U60.13
156: J58.9, U60.8
157: J58.8, U60.23
158: J58.7, U60.9
159: J58.6, U60.12
160: J58.5, U60.14
161: J58.4, R162.1, U60.16
162: J59.14, U60.27
163: J59.15, U60.28
164: J59.16, U60.33
A0: J4.5, U5.11
A1: J4.6, U5.10
A2: J4.7, U5.6
A3: J4.8, U5.5
A4: J4.9, U5.4
A5: J4.10, U5.26
A6: J7.5, U8.11
A7: J7.6, U8.10
A8: J7.7, U8.6
A9: J7.8, U8.5
A10: J7.9, U8.4
A11: J7.10, U8.26
A12: J11.5, U12.11
A13: J11.6, U12.10
A14: J11.7, U12.6
A15: J11.8, U12.5
A16: J11.9, U12.4
A17: J11.10, U12.26
A18: J15.5, U16.11
A19: J15.6, U16.10
A20: J15.7, U16.6
A21: J15.8, U16.5
A22: J15.9, U16.4
A23: J15.10, U16.26
A24: J19.5, U20.11
A25: J19.6, U20.10
A26: J19.7, U20.6
A27: J19.8, U20.5
A28: J19.9, U20.4
A29: J19.10, U20.26
A30: J23.5, U24.11
A31: J23.6, U24.10
A32: J23.7, U24.6
A33: J23.8, U24.5
A34: J23.9, U24.4
A35: J23.10, U24.26
A36: J27.5, U28.11
A37: J27.6, U28.10
A38: J27.7, U28.6
A39: J27.8, U28.5
A40: J27.9, U28.4
A41: J27.10, U28.26
A42: J31.5, U32.11
A43: J31.6, U32.10
A44: J31.7, U32.6
A45: J31.8, U32.5
A46: J31.9, U32.4
A47: J31.10, U32.26
A48: J35.5, U36.11
A49: J35.6, U36.10
A50: J35.7, U36.6
A51: J35.8, U36.5
A52: J35.9, U36.4
A53: J35.10, U36.26
A54: J39.5, U40.11
A55: J39.6, U40.10
A56: J39.7, U40.6
A57: J39.8, U40.5
A58: J39.9, U40.4
A59: J39.10, U40.26
A60: J43.5, U44.11
A61: J43.6, U44.10
A62: J43.7, U44.6
A63: J43.8, U44.5
A64: J43.9, U44.4
A65: J43.10, U44.26
A66: J47.5, U48.11
A67: J47.6, U48.10
A68: J47.7, U48.6
A69: J47.8, U48.5
A70: J47.9, U48.4
A71: J47.10, U48.26
A72: J51.5, U52.11
A73: J51.6, U52.10
A74: J51.7, U52.6
A75: J51.8, U52.5
A76: J51.9, U52.4
A77: J51.10, U52.26
A78: J55.5, U56.11
A79: J55.6, U56.10
A80: J55.7, U56.6
A81: J55.8, U56.5
A82: J55.9, U56.4
A83: J55.10, U56.26
A84: J59.5, U60.11
A85: J59.6, U60.10
A86: J59.7, U60.6
A87: J59.8, U60.5
A88: J59.9, U60.4
A89: J59.10, U60.26
CHG: D1.C, U1.1
CHG1: D5.C, U2.1
CHG2: D8.C, U9.1
CHG3: D11.C, U13.1
CHG4: D14.C, U17.1
CHG5: D17.C, U21.1
CHG6: D20.C, U25.1
CHG7: D23.C, U29.1
CHG8: D26.C, U33.1
CHG9: D29.C, U37.1
CHG10: D32.C, U41.1
CHG11: D35.C, U45.1
CHG12: D38.C, U49.1
CHG13: D41.C, U53.1
CHG14: D44.C, U57.1
CHIP_PU: J4.1, Q2.3, R2.1, S1.4, U5.3
CHIP_PU1: J7.1, Q4.3, R16.1, S3.4, U8.3
CHIP_PU2: J11.1, Q6.3, R29.1, S5.4, U12.3
CHIP_PU3: J15.1, Q8.3, R40.1, S7.4, U16.3
CHIP_PU4: J19.1, Q10.3, R51.1, S9.4, U20.3
CHIP_PU5: J23.1, Q12.3, R62.1, S11.4, U24.3
CHIP_PU6: J27.1, Q14.3, R73.1, S13.4, U28.3
CHIP_PU7: J31.1, Q16.3, R84.1, S15.4, U32.3
CHIP_PU8: J35.1, Q18.3, R95.1, S17.4, U36.3
CHIP_PU9: J39.1, Q20.3, R106.1, S19.4, U40.3
CHIP_PU10: J43.1, Q22.3, R117.1, S21.4, U44.3
CHIP_PU11: J47.1, Q24.3, R128.1, S23.4, U48.3
CHIP_PU12: J51.1, Q26.3, R139.1, S25.4, U52.3
CHIP_PU13: J55.1, Q28.3, R150.1, S27.4, U56.3
CHIP_PU14: J59.1, Q30.3, R161.1, S29.4, U60.3
CIPO: J4.13, U5.31
CIPO1: J7.13, U8.31
CIPO2: J11.13, U12.31
CIPO3: J15.13, U16.31
CIPO4: J19.13, U20.31
CIPO5: J23.13, U24.31
CIPO6: J27.13, U28.31
CIPO7: J31.13, U32.31
CIPO8: J35.13, U36.31
CIPO9: J39.13, U40.31
CIPO10: J43.13, U44.31
CIPO11: J47.13, U48.31
CIPO12: J51.13, U52.31
CIPO13: J55.13, U56.31
CIPO14: J59.13, U60.31
COPI: J4.12, U5.30
COPI1: J7.12, U8.30
COPI2: J11.12, U12.30
COPI3: J15.12, U16.30
COPI4: J19.12, U20.30
COPI5: J23.12, U24.30
COPI6: J27.12, U28.30
COPI7: J31.12, U32.30
COPI8: J35.12, U36.30
COPI9: J39.12, U40.30
COPI10: J43.12, U44.30
COPI11: J47.12, U48.30
COPI12: J51.12, U52.30
COPI13: J55.12, U56.30
COPI14: J59.12, U60.30
D+: J5.D+, U4.3
D+1: J8.D+, U7.3
D+2: J12.D+, U11.3
D+3: J16.D+, U15.3
D+4: J20.D+, U19.3
D+5: J24.D+, U23.3
D+6: J28.D+, U27.3
D+7: J32.D+, U31.3
D+8: J36.D+, U35.3
D+9: J40.D+, U39.3
D+10: J44.D+, U43.3
D+11: J48.D+, U47.3
D+12: J52.D+, U51.3
D+13: J56.D+, U55.3
D+14: J60.D+, U59.3
D-: J5.D-, U4.4
D-1: J8.D-, U7.4
D-2: J12.D-, U11.4
D-3: J16.D-, U15.4
D-4: J20.D-, U19.4
D-5: J24.D-, U23.4
D-6: J28.D-, U27.4
D-7: J32.D-, U31.4
D-8: J36.D-, U35.4
D-9: J40.D-, U39.4
D-10: J44.D-, U43.4
D-11: J48.D-, U47.4
D-12: J52.D-, U51.4
D-13: J56.D-, U55.4
D-14: J60.D-, U59.4
DTR: Q2.1, R17.1, U4.23
DTR1: Q4.1, R13.1, U7.23
DTR2: Q6.1, R26.1, U11.23
DTR3: Q8.1, R37.1, U15.23
DTR4: Q10.1, R48.1, U19.23
DTR5: Q12.1, R59.1, U23.23
DTR6: Q14.1, R70.1, U27.23
DTR7: Q16.1, R81.1, U31.23
DTR8: Q18.1, R92.1, U35.23
DTR9: Q20.1, R103.1, U39.23
DTR10: Q22.1, R114.1, U43.23
DTR11: Q24.1, R125.1, U47.23
DTR12: Q26.1, R136.1, U51.23
DTR13: Q28.1, R147.1, U55.23
DTR14: Q30.1, R158.1, U59.23
EN: J2.2, R8.2, U3.3
EN1: J6.2, R20.2, U6.3
EN2: J10.2, R31.2, U10.3
EN3: J14.2, R42.2, U14.3
EN4: J18.2, R53.2, U18.3
EN5: J22.2, R64.2, U22.3
EN6: J26.2, R75.2, U26.3
EN7: J30.2, R86.2, U30.3
EN8: J34.2, R97.2, U34.3
EN9: J38.2, R108.2, U38.3
EN10: J42.2, R119.2, U42.3
EN11: J46.2, R130.2, U46.3
EN12: J50.2, R141.2, U50.3
EN13: J54.2, R152.2, U54.3
EN14: J58.2, R163.2, U58.3
GND: C1.2, C2.2, C3.2, C6.2, C7.2, C10.2, C19.2, D3.C, J3.1, J4.4, J5.GND, JP2.1, R6.1, R7.1, R9.1, S1.1, S2.1, U1.2, U3.2, U4.2, U4.PAD, U5.1, U5.15, U5.38, U5.GND, U5.P$1, U5.P$2, U5.P$3, U5.P$4, U5.P$5, U5.P$6, U5.P$7, U5.P$8
GND1: C4.2, C5.2, C8.2, C9.2, C11.2, C12.2, C13.2, D6.C, J1.1, J7.4, J8.GND, JP1.1, R10.1, R12.1, R22.1, S3.1, S4.1, U2.2, U6.2, U7.2, U7.PAD, U8.1, U8.15, U8.38, U8.GND, U8.P$1, U8.P$2, U8.P$3, U8.P$4, U8.P$5, U8.P$6, U8.P$7, U8.P$8
GND2: C14.2, C15.2, C16.2, C17.2, C18.2, C20.2, C21.2, D9.C, J9.1, J11.4, J12.GND, JP3.1, R23.1, R25.1, R33.1, S5.1, S6.1, U9.2, U10.2, U11.2, U11.PAD, U12.1, U12.15, U12.38, U12.GND, U12.P$1, U12.P$2, U12.P$3, U12.P$4, U12.P$5, U12.P$6, U12.P$7, U12.P$8
GND3: C22.2, C23.2, C24.2, C25.2, C26.2, C27.2, C28.2, D12.C, J13.1, J15.4, J16.GND, JP4.1, R34.1, R36.1, R44.1, S7.1, S8.1, U13.2, U14.2, U15.2, U15.PAD, U16.1, U16.15, U16.38, U16.GND, U16.P$1, U16.P$2, U16.P$3, U16.P$4, U16.P$5, U16.P$6, U16.P$7, U16.P$8
GND4: C29.2, C30.2, C31.2, C32.2, C33.2, C34.2, C35.2, D15.C, J17.1, J19.4, J20.GND, JP5.1, R45.1, R47.1, R55.1, S9.1, S10.1, U17.2, U18.2, U19.2, U19.PAD, U20.1, U20.15, U20.38, U20.GND, U20.P$1, U20.P$2, U20.P$3, U20.P$4, U20.P$5, U20.P$6, U20.P$7, U20.P$8
GND5: C36.2, C37.2, C38.2, C39.2, C40.2, C41.2, C42.2, D18.C, J21.1, J23.4, J24.GND, JP6.1, R56.1, R58.1, R66.1, S11.1, S12.1, U21.2, U22.2, U23.2, U23.PAD, U24.1, U24.15, U24.38, U24.GND, U24.P$1, U24.P$2, U24.P$3, U24.P$4, U24.P$5, U24.P$6, U24.P$7, U24.P$8
GND6: C43.2, C44.2, C45.2, C46.2, C47.2, C48.2, C49.2, D21.C, J25.1, J27.4, J28.GND, JP7.1, R67.1, R69.1, R77.1, S13.1, S14.1, U25.2, U26.2, U27.2, U27.PAD, U28.1, U28.15, U28.38, U28.GND, U28.P$1, U28.P$2, U28.P$3, U28.P$4, U28.P$5, U28.P$6, U28.P$7, U28.P$8
GND7: C50.2, C51.2, C52.2, C53.2, C54.2, C55.2, C56.2, D24.C, J29.1, J31.4, J32.GND, JP8.1, R78.1, R80.1, R88.1, S15.1, S16.1, U29.2, U30.2, U31.2, U31.PAD, U32.1, U32.15, U32.38, U32.GND, U32.P$1, U32.P$2, U32.P$3, U32.P$4, U32.P$5, U32.P$6, U32.P$7, U32.P$8
GND8: C57.2, C58.2, C59.2, C60.2, C61.2, C62.2, C63.2, D27.C, J33.1, J35.4, J36.GND, JP9.1, R89.1, R91.1, R99.1, S17.1, S18.1, U33.2, U34.2, U35.2, U35.PAD, U36.1, U36.15, U36.38, U36.GND, U36.P$1, U36.P$2, U36.P$3, U36.P$4, U36.P$5, U36.P$6, U36.P$7, U36.P$8
GND9: C64.2, C65.2, C66.2, C67.2, C68.2, C69.2, C70.2, D30.C, J37.1, J39.4, J40.GND, JP10.1, R100.1, R102.1, R110.1, S19.1, S20.1, U37.2, U38.2, U39.2, U39.PAD, U40.1, U40.15, U40.38, U40.GND, U40.P$1, U40.P$2, U40.P$3, U40.P$4, U40.P$5, U40.P$6, U40.P$7, U40.P$8
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

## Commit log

2020-10-09 starting from 32d version, local libarary work done
    [ESP32_Thing_Plus_UFL.brd, ESP32_Thing_Plus_UFL.sch]
2020-10-09 switched to u.fl module and modified the CP2104 VBUS input
    -u.fl module swapped out
    -added standoffs and new measures
    -moved product name and logo to top of board
    -added in voltage split circuit to vbus input to CP2104
    -connected VREGIN pin on CP2104 to 3.3V (previously was connected to vbus)
    -changed value of R1 to 2.2K
    -added C2 and C3 for additional decoupling caps near CP2104
    [ESP32_Thing_Plus_UFL.brd, ESP32_Thing_Plus_UFL.sch]
2020-10-13 post design review changes
    -changed R1 to a 10K (pullup on RSTB on CP2102)
    -nudged U1 (and nearby passives) down to make more space around pin 13 LED.
    -changed all 0402 "standard" footprints to use the "tight". re-routed as necessary.
    -made all 4.7uF caps the same 0402 part
    -made all 1.0uF caps (qty 2) the same 0402 part (X5R)
    [ESP32_Thing_Plus_UFL.brd, ESP32_Thing_Plus_UFL.sch]
2020-10-13 new buzzards, swapped out Miso/Mosi naming
    [ESP32_Thing_Plus_UFL.brd, ESP32_Thing_Plus_UFL.sch]
2020-10-14 aesthetic changes from post review review
    -Change CIPO and COPI pin names in symbol to SDI/SDO
    -Updated product name bottom silk to include "32"
    -Removed extra top silk flame logo at bottom right (since we had room for the full name and flame logo at the top.
    -changed silk names for DI/DO to SDI/SDO for more consitency in schematic/board naming.
    [ESP32_Thing_Plus_UFL.brd, ESP32_Thing_Plus_UFL.sch]
2020-10-14 Run of checklist catches
    -vector font in sch
    -flag label on NET "0"
    -changes top silk on RST pin to include active low marking
    [ESP32_Thing_Plus_UFL.brd, ESP32_Thing_Plus_UFL.sch]
2020-10-15 changing library part names/descriptions to the 32EU
    [ESP32_Thing_Plus_UFL.brd, ESP32_Thing_Plus_UFL.sch]
2020-10-15 updated ESP32EU footprint to match gnd pad array from datasheet
    -also added gnd pours to top and bottom copper
    [ESP32_Thing_Plus_UFL.brd, ESP32_Thing_Plus_UFL.sch]
2020-10-16 Increased top and bottom ground pour isolate to 0.01"
    This provides more clearance and prevents the tStop (mask opening) from exposing any nearby ground pour.
    [ESP32_Thing_Plus_UFL.brd]
2020-10-16 removed dimension of module that was accidentally on tPlace
    [ESP32_Thing_Plus_UFL.brd, ESP32_Thing_Plus_UFL.sch]
2020-10-16 Production panel and gerbers v10
    [ESP32_Thing_Plus_UFL-Panel.brd]

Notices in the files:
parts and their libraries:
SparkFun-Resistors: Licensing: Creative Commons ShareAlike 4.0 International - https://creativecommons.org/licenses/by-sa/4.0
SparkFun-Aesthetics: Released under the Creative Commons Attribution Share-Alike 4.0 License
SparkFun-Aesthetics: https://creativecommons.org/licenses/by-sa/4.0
